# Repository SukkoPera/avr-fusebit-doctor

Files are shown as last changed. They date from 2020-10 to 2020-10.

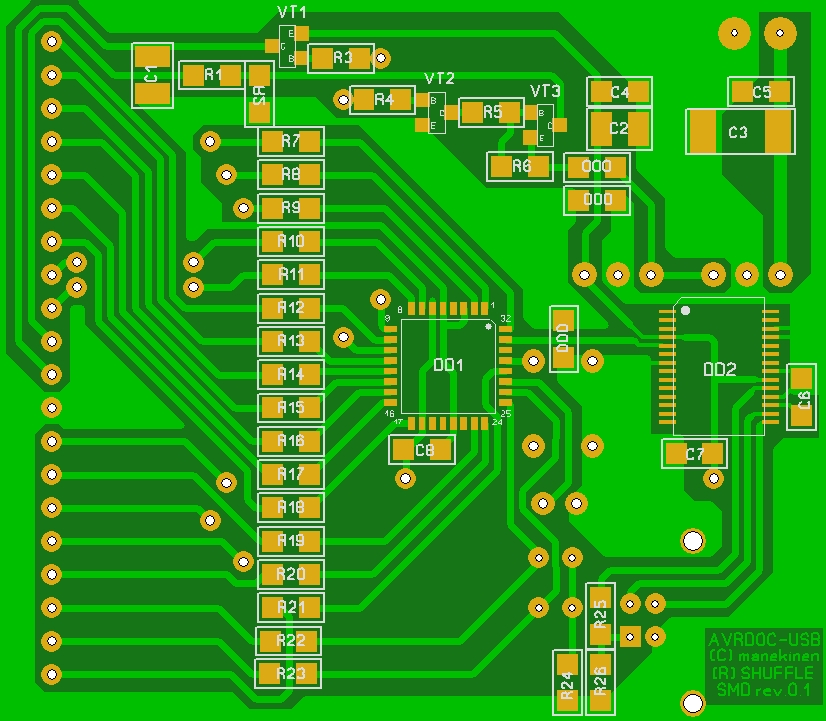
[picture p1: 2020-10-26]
SMD-pcb/avrdoc_main/shuffle_avrdocusb_botscr.JPG

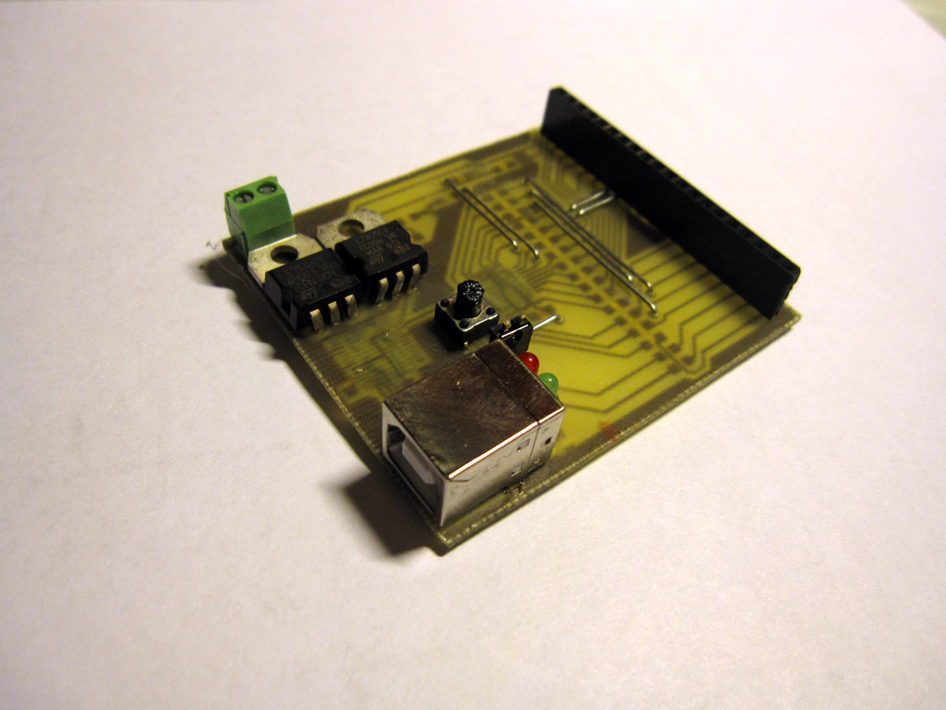
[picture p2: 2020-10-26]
SMD-pcb/avrdoc_photos/1_avrdoc_usb_top1.JPG

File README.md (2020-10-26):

# ATmega Fusebit Doctor (HVPP + HVSP): Fix the fusebits

ATmega Fusebit Doctor is a device for repairing dead ATmega (and ATtiny since v2.04) family AVR microcontrollers by writing correct fusebits. Most common mistakes or problems are a wrong clock source (CKSEL fusebits), disabled SPI programming (SPIEN fuse) or disabled reset pin (RSTDISBL fuse). This simple and cheap circuit will fix you uC in a fraction of a second. If in first case we can help ourself with clock generator, then in 2nd and 3rd cases bring uC back to life is impossible with standard serial programmer. Most of people do not decide to build parallel programmer because its inconvenient and its cheaper and faster to buy new uC.

Originally ATmega Fusebit Doctor was a project by Paweł Kisielewski (Manekinen). One day his website disappeared and the project was at risk of being lost forever. Luckily, I (SukkoPera) managed to salvage it with the help of Wayback Machine and decided to put it on GitHub, trying to preserve all the original contents and history. I hope people will contribute and help make it an even better project.

## High voltage programming
This circuit uses the parallel and serial high-voltage programming method. With those methods, we can talk to our "dead" chips which have reset or isp disabled:
- HVPP = High Voltage Parallel Programming
- HVSP = High Voltage Serial Programming.

## Supported chips
Code to this point supports 145 chips, but not all have been tested. Untested ones are listed *in italic*.

### 1kB
AT90s1200, *ATtiny11*, *ATtiny12*, ATtiny13/A, *ATtiny15*

### 2kB
ATtiny2313/A, *ATtiny24/A*, ATtiny26, *ATtiny261/A*, *ATtiny28*, *AT90s2333*, *ATtiny22*, ATtiny25, AT90s2313, *AT90s2323*, *AT90s2343*

### 4kB
ATmega48/A, *ATmega48P/PA*, ATtiny461/A, *ATtiny43U*, *ATtiny4313*, *ATtiny44/A*, *ATtiny48*, *AT90s4433*, *AT90s4414*, *AT90s4434*, ATtiny45

### 8kB
ATmega8515, ATmega8535, ATmega8/A, ATmega88/A, *ATmega88P/PA*, *AT90pwm1*, *AT90pwm2*, *AT90pwm2B*, *AT90pwm3*, AT90pwm3B, *AT90pwm81*, *AT90usb82*, *ATtiny84*, ATtiny85, *ATtiny861/A*, *ATtiny87*, *ATtiny88*, AT90s8515, *AT90s8535*

### 16kB
ATmega16/A, *ATmega16U2*, *ATmega16U4*, *ATmega16M1*, *ATmega161*, ATmega162, *ATmega163*, *ATmega164A*, *ATmega164P/PA*, *ATmega165A/P/PA*, ATmega168/A, *ATmega168P/PA*, *ATmega169A/PA*, *ATtiny167*, *AT90pwm216*, *AT90pwm316*, *AT90usb162*

### 32kB
ATmega32/A, *ATmega32C1*, *ATmega323/A*, *ATmega32U2*, *ATmega32U4*, *ATmega32U6*, *ATmega32M1*, *ATmega324A*, *ATmega324P*, ATmega324PA, *ATmega325*, *ATmega3250*, *ATmega325A/PA*, *ATmega3250A/PA*, *ATmega328*, ATmega328P, *ATmega329*, *ATmega3290*, *ATmega329A/PA*, *ATmega3290A/PA*, *AT90can32*

### 64kB
*ATmega64/A*, *ATmega64C1*, *ATmega64M1*, *ATmega649*, *ATmega6490*, *ATmega649A/P*, *ATmega6490A/P*, *ATmega640*, ATmega644/A, ATmega644P/PA, *ATmega645*, *ATmega645A/P*, *ATmega6450*, *ATmega6450A/P*, *AT90usb646*, *AT90usb647*, *AT90can64*

### 128kB
*ATmega103*, ATmega128/A, ATmega1280, *ATmega1281*, *ATmega1284*, *ATmega1284P*, *AT90usb1286*, *AT90usb1287*, *AT90can128*

### 256kB
ATmega2560, ATmega2561

## About
Just put your dead mega in socket, press the START button, and enjoy your good-as-new processor. There are three slots on board, for most common AVR’s, pins compatible with: ATmega8, ATmega16, ATtiny2313. There is also an extra goldpin connector with all signals so you can attach adapters:
- "#1 adapter" as HVPP extension, for 20pin ATtiny26 compatible and 40pin ATmega8515 compatible processors.
- "HVSP adapter" for 8pin and 14pin HVSP processors

Or make your own adapters for other types of processors, in trough-hole or surface-mounted, you can use the breadboard for this – just connect signals to correct pins. How? Check your AVR datasheet, go to "memory programming” and then "parallel programming” – check the signal names, all signals are described under the DIP40 slot. In doctor memory there is a lot of free space so project may be developed all the time. One sided PCB with 55mm x 92mm dimensions. On top side you need to solder several jumpers, or, make this PCB as double sided – choose yourself.

Resistors from R7 to R23 may be in 100ohm to 10K, but i suggest from 470ohm to 1K.

ATTENTION! While mounting the DIP40 slot, you must to remove it pins from 29 to 37. These pins must not have electrical contact with inserted uC pins, traces runs there only to make the board smaller (onesided). Take a look at pic on the left, these you must remove from slot.

## Usage
The ALLOW ERASE jumper allows doctor to erase whole flash and eeprom memory, if it is open, doctor will never erase memory but may not cure device if lockbits are enabled, so you choose.

After insert dead uC and press the START button, doctor will initiate the parallel or serial high-voltage programming mode. This is chosen automatically, device will recognize HVSP adapter and start to work in HVSP mode. After that, doctor wait for high state at RDY/BSY line. Then, read device signature and check if it supports it. Next, memory erase is performed if user allows that. Then lockbits are checked, and if they not blocking device, doctor sets all fusebits to fabric, having regard to whether there are extended fusebits or not. Some of older AVR have only one byte of fuses – LOW – and this is also included. After
fusebits are verified, the proper leds is flashed.

### Leds explanation
- Green on – patient successfully cured, fusebits repaired. If lockbits are enabled, just verify fusebits with factory ones – and if they ok – light up green.
- Red on – signature problem, can’t read, no device in socket, or no such signature in database.
- Green flashing – signature ok, fusebits are wrong. Lockbits enabled, chip erase permission required (read below).
- Red flashing – signature ok, no lockbits, but for some reason can’t write new fusebits.

## Terminal
Note that terminal is not needed, device works without pc, and all we want to know we get from leds.

You can find extra RS232 output, and connecting this to the terminal, sends all information about fixing process – see exemplary printscreens in gallery. All the info is sent "on the fly" via uart. Use proper converter to connect this with pc. If you have COM port for RS232, use MAX232 based converter (eg this). If you are using laptop, use a USB converter.

### Terminal settings
- Baudrate: 4800
- Parity: none
- Data bits: 8
- Stop bits: 1
- Handshake: none

## Other
Use one of the following microcontrollers as the doctor-chip: ATmega8, ATmega88, ATmega88P, ATmega168, ATmega168P, ATmega328, ATmega328P – and their newer/low-voltage "A” or "L” versions.

Use stabilized 12V supply voltage. Higher voltage can damage the patient chip!

Code was written based on high-voltage parallel and serial programming section of datasheet of suitable AVRs.

### Fusebits
Internal 1MHz clock, and enabled EESAVE bit – see README file.

If you use a brand new chips as doctor, you don’t need to change anything – 1MHz clock is already set as default. EESAVE bit is optional. It disallows to erase the eeprom when firmware is actualized, eeprom is used to store the fixed chips counter which is sent trough UART.

## Manual Mode
UPDATE 2.1X ADDS NEW FUNCTIONALITY!

Send your own fuses and locks trough terminal, talk with chips with broken signature. If you connect terminal TX pin to PCB RX pin – manual mode will be enabled automatically. This requires TX-terminal pin to be HIGH and OUTPUT when idle. It must pull up the 10K pulldown. If this condition is not met, doctor will work in normal – automatic mode.

### HowTo
First, doctor will read signature. And if fail, it will ask to type signature manually.

Type two last bytes of signature in HEX (4 chars) and hit enter.

Then doctor will try to read the chip depending on given signature.
When this succeeds, select an option:
1. Write fusebits: this will perform a fuse write cycle with fuse-values from buffer (default).
2. Modify fusebits: this will let you to type fuses manually, values in buffer will update. Type one byte in HEX (2 chars) and hit enter. Repeat for each byte (if exist).
3. Set lockbits: type new lock value in HEX (2 chars) and hit enter – do this with caution! Remember that unused bits are always 1! E.g. if want to enable LB1 and LB2, type FC (11111100).
4. Erase the chip: This will just erase the chip and locks, it requires the "allow erase" jumper for safety.
5. End: exit programming and drop voltages, now you can safely remove the chip.

Do not pay attention to the LEDs when in manual mode – they will just blink randomly :).

## License
Manekinen's original licensing terms say:

> Any modifications allowed, do not remove this README! from archive. Do not remove info from pcb and code.
>
> Any usage of this project in commercial/profit purposes is prohibited.

They are a bit vague but they seem to match [CC BY-NC-SA 4.0](https://creativecommons.org/licenses/by-nc-sa/4.0/?ref=chooser-v1) pretty well, so I think that can be used whenever a formal license is needed.

Note that the firmware sources are not available. They have never been disclosed as far as I know.

## FAQ – Frequently Asked Questions (and Answers)

Q: No sign of life, no leds are working.
A: Critical bugs on pcb, poorly programmed chip.

Q: Red led is on.
A: Chip si not recognized. Make a voltage measurements. In idle, measure voltages on +12 RESET and +5 SUPPLY at female goldpin connector – you should get 0V or close to 0V on both. After the START button is pressed, you should get close to +12V and 5V for one second. If not, check transistors, if they are ok and if they are soldered ok.

Q: Red led is on.
A: Bugs on pcb, traces are packed densely and its very possible that you have invisible gap, shortcut, or dry joint. Check everything with multimeter, but PRECISELY.

Q: Red led is on.
A: Connect device to the terminal to get repair log. Press start to receive infos.

Q: Received "Init programming...” and nothing more – OR – received signature is "00 01 02” or "FF FF FF”.
A: Chip is broken, or there still are bugs on pcb – look above.

Q: Received signature is "1E 90 00", "1E 1E 1E", or something familiar (meaningful data).
A: Chip is good, it initiates, look for shortcuts on DATA, BS, XA lines.

Q: Green led is on / "Verifying... – OK!" received, but chips don’t work with standard programmer.
A: You can be 100% sure that fuses are fixes, chip have hardware ISP damaged or it have some other damage.

Q: What are "Read Signature... FAIL!" and "Trying T2313 pinout... OK" doing in log?
A: All the 20pin chips need to be treated individually. First, device tries to read chip with standard schematic, and if it fails ("FAIL!”), then it tries to use schematic for 20pin T2313 compatible chips and then chip is read properly. This is normal behavior, this not a bug.

Q: What are `<[2J` trashes doing in log?
A: This is a terminal clear screen sequence, turn on the "VT-100” emulation in terminal settings.

Q: I’m trying to type data into terminal but no chars appearing.
A:Make sure you set handshake to NONE in terminal settings.

Q: After typing data into the terminal, I can’t confirm them with return key and can’t type next ones.
A: When pressing return, your terminal must have to send the CRLF chars, if not, check your settings.

Q: This still doesn’t help me, I tried everything but still have the problem.
A: Ask in comments below :) Post firmware version and pcb version with which you try to work, paste the repair log.

Q: Are all those 1K series resistors (R7 through R23) really needed here?
A: No, you can build the circuit without them. But remember, if for some reason out patient will not enter in the programming mode and continue with its code, then logic state conflict will occur between two microcontrollers which can damage them permanently. These resistors are to protect the circuit against such situations. I strongly recommend to build it exactly as schematic says.

Q: Pull-down resistors for 12V and 5V lines (R24 and R27) are heating up quite strongly in manual mode, and whole circuit takes more power, can i change them for something higher value?
A: Yes, but circuit can work incorrectly with some of the patients. When idle, voltages should be near 0V, and when powering on or off, their edges should have proper
steepness to provide good timing (see entering high voltage programming in datasheet). Because only simple bipolar transistors are used, these resistors guarantee above requirements. The interesting case is an ATtiny2313 problem when all the fuses were correctly burned, without one, the RSTDISBL. As it showed up, because of bad edges of 12V reset voltage, this uC although was working in parallel mode, but not in high voltage, so it was not allowing to change that fuse – this is my own interpretation so i can be wrong.

Q: My chip is read properly but doctor can not write new fuses, allow erase is enabled.
A: If the ISP programmer acts the same way, then your chip is damaged, nothing can do.

Q: Without a patient, circuit acts awkward, it freezes, and goes on when i put my finger near the traces.
A: This circuit is not meant to be used without a patient. It acts in such way because when entering in programming mode, it is waiting for a high state on the RDY pin from patient. This pin is not pulled down and works as high impedance input, so electrostatic charge from your finger is read as high state and code goes on further.

Q: Chip names are not appearing in the log, i see "no names in 8kB ver" instead.
A: Chip names are not displayed in 8kB versions of the firmware, i.e. for ATmega8 and ATmega88 – because names don’t fit in such memory space. If you want the names, use ATmega168 or ATmega328 chip and burn proper firmware. ALWAYS use the newest version of the firmware. Hex and bin files are the flash memory files, use one of them. No need to program eeprom memory.

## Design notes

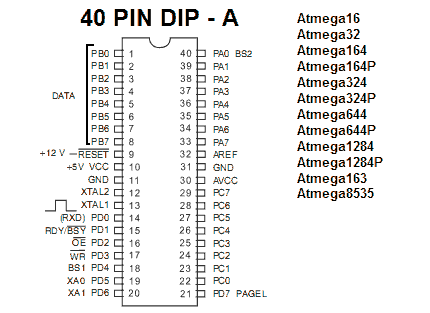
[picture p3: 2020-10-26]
sockets/40pin-onboard.gif

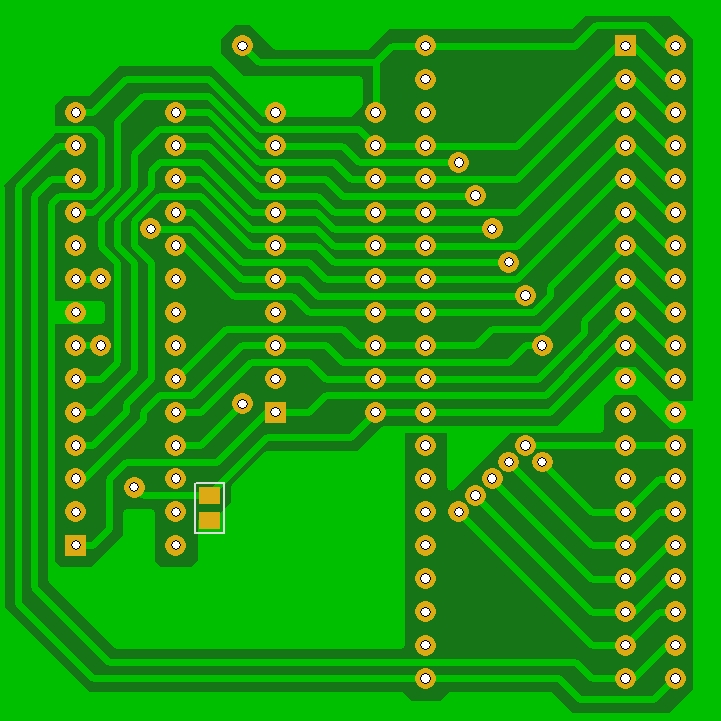
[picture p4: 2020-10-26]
SMD-pcb/avrdoc_adapter/shuffle_avrdocusb_botscr.JPG

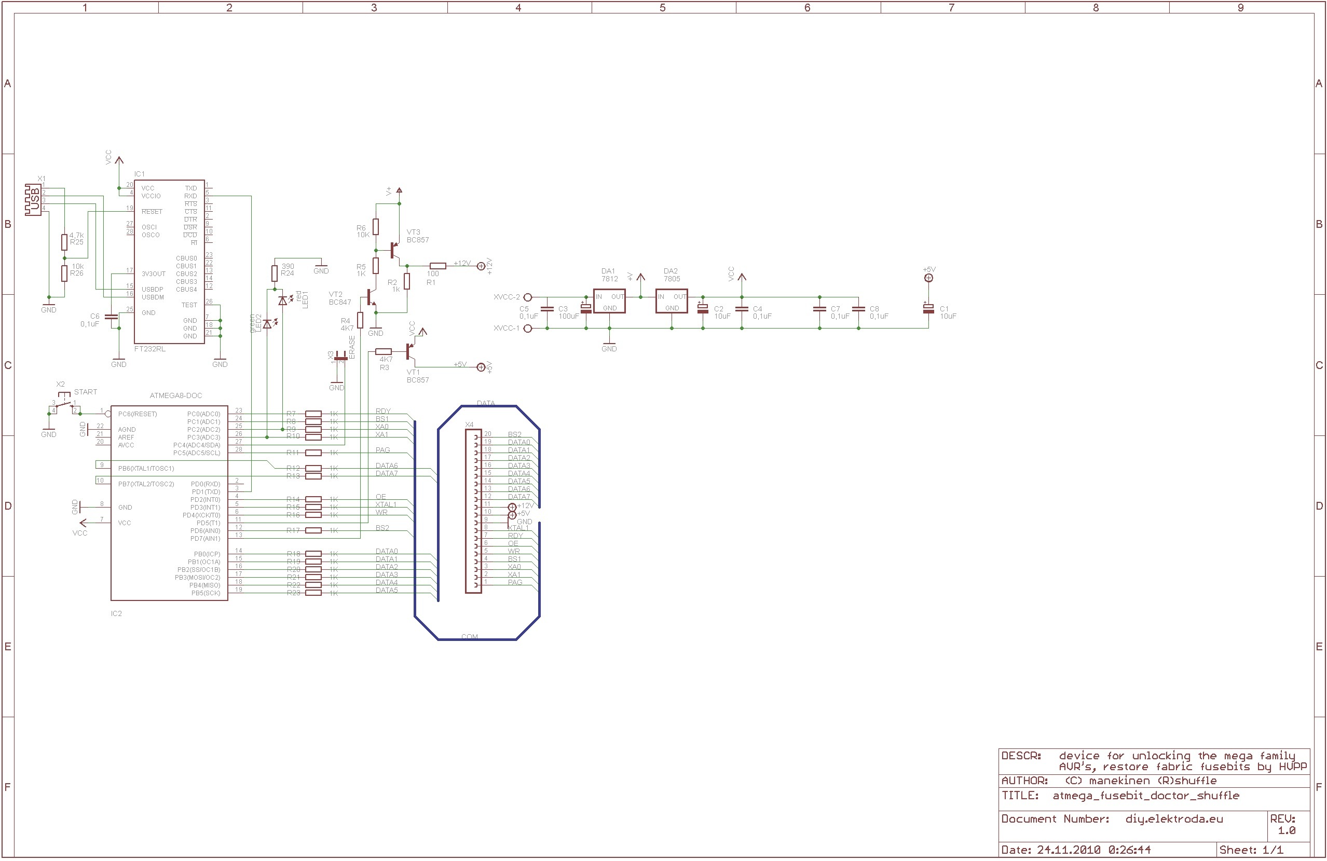
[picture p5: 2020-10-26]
SMD-pcb/shuffle_avrdocusb_scheme.jpg

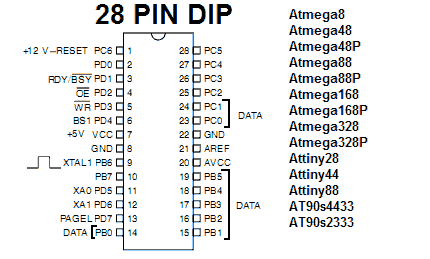
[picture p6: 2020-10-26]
sockets/28pin-onboard.gif

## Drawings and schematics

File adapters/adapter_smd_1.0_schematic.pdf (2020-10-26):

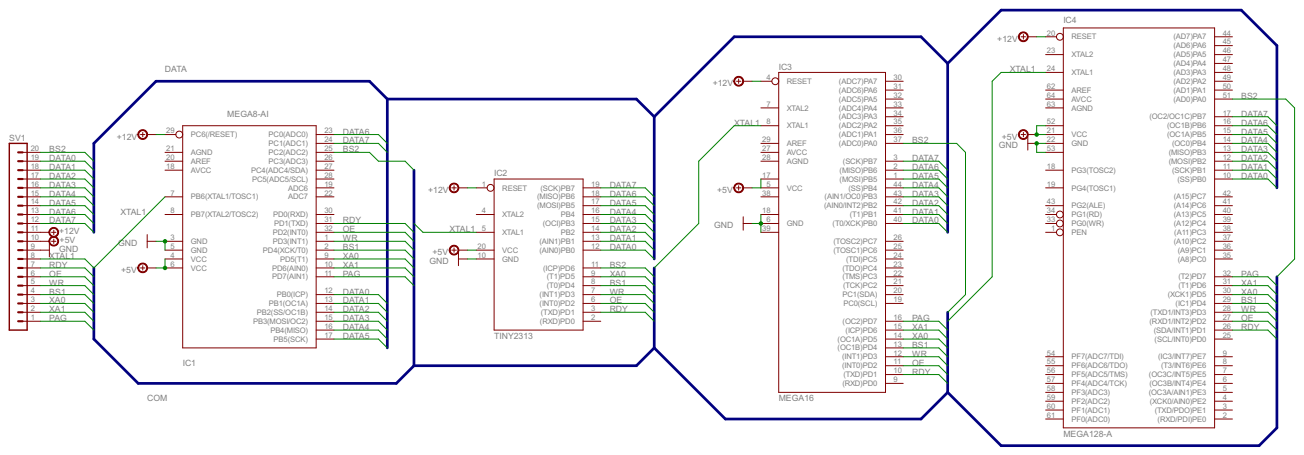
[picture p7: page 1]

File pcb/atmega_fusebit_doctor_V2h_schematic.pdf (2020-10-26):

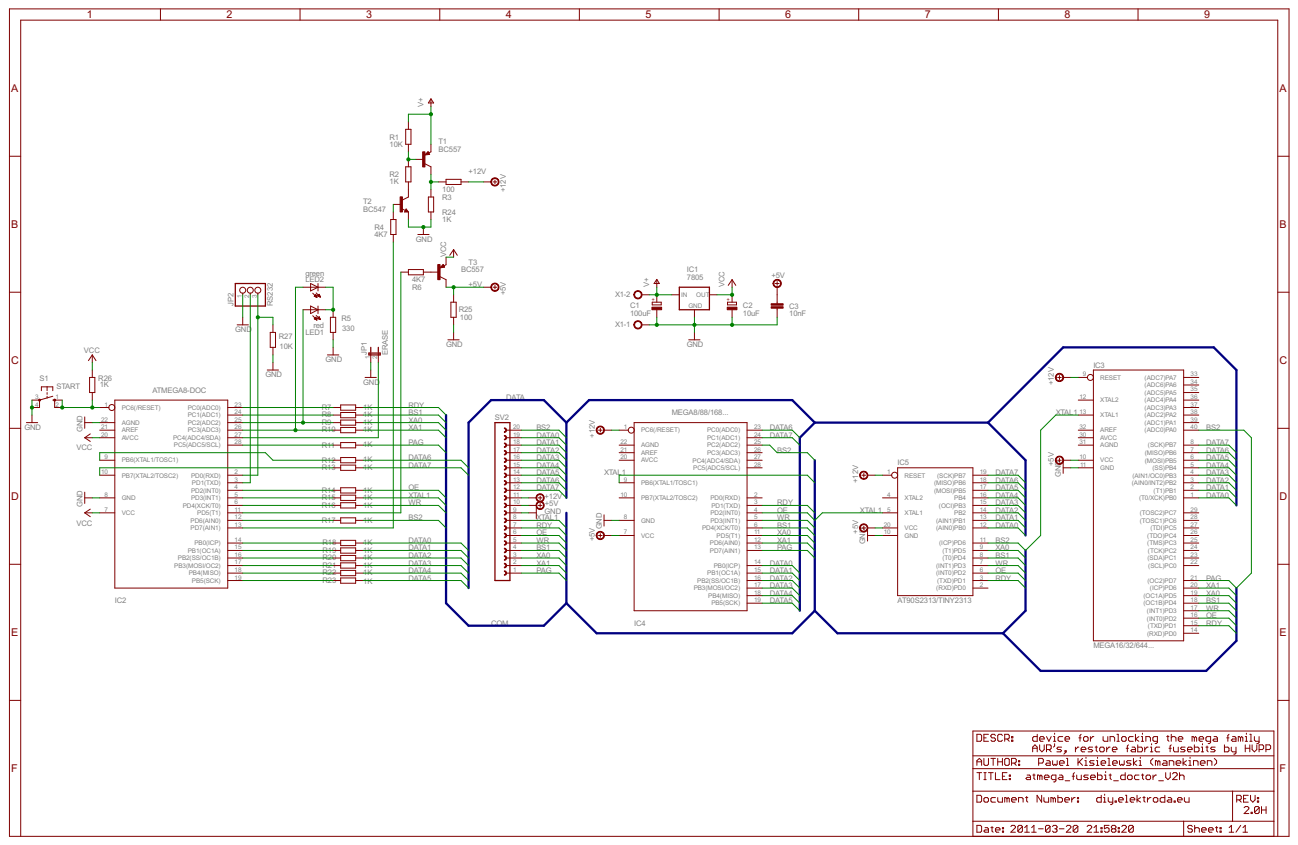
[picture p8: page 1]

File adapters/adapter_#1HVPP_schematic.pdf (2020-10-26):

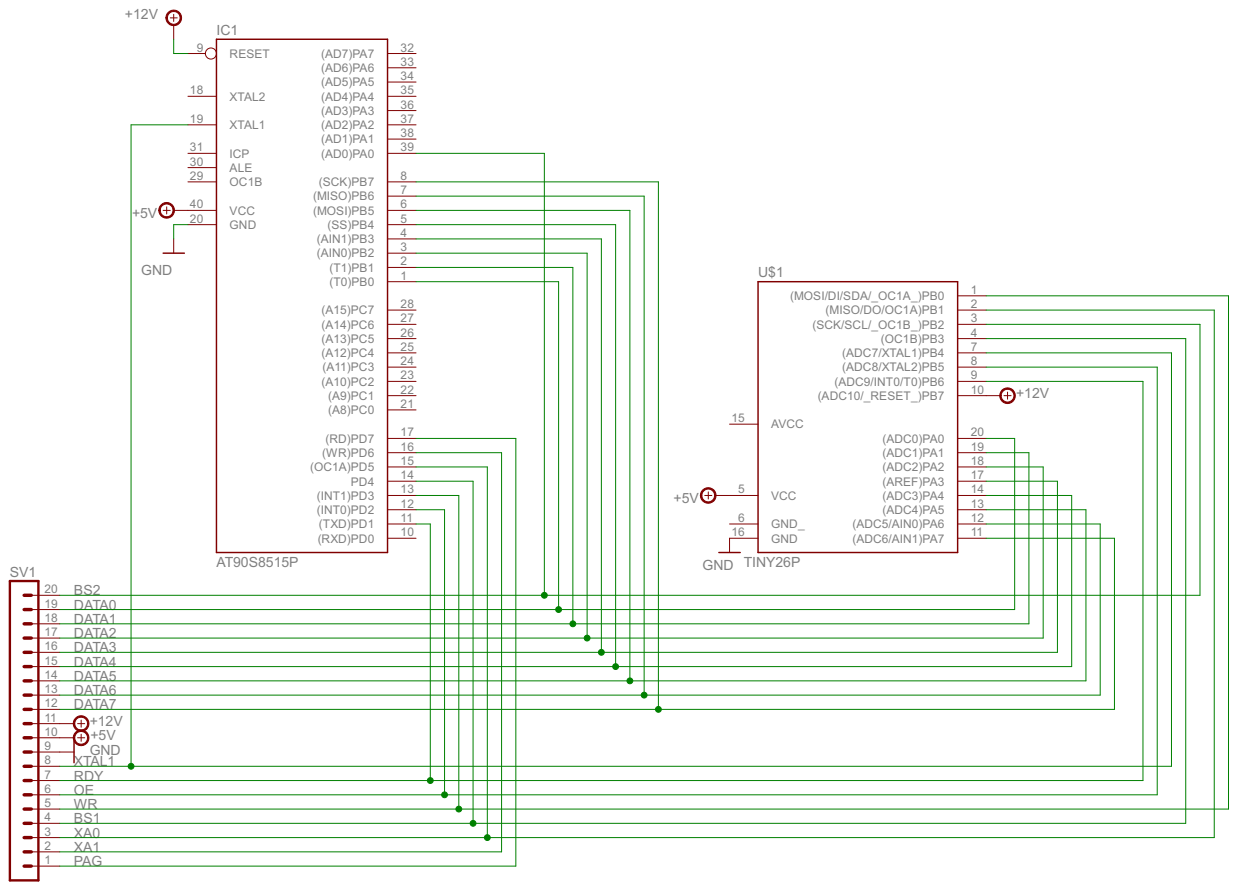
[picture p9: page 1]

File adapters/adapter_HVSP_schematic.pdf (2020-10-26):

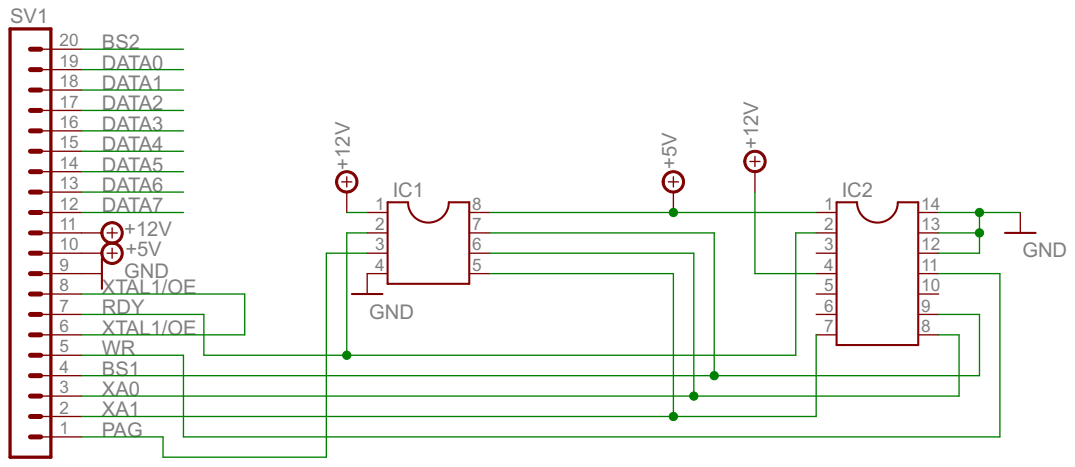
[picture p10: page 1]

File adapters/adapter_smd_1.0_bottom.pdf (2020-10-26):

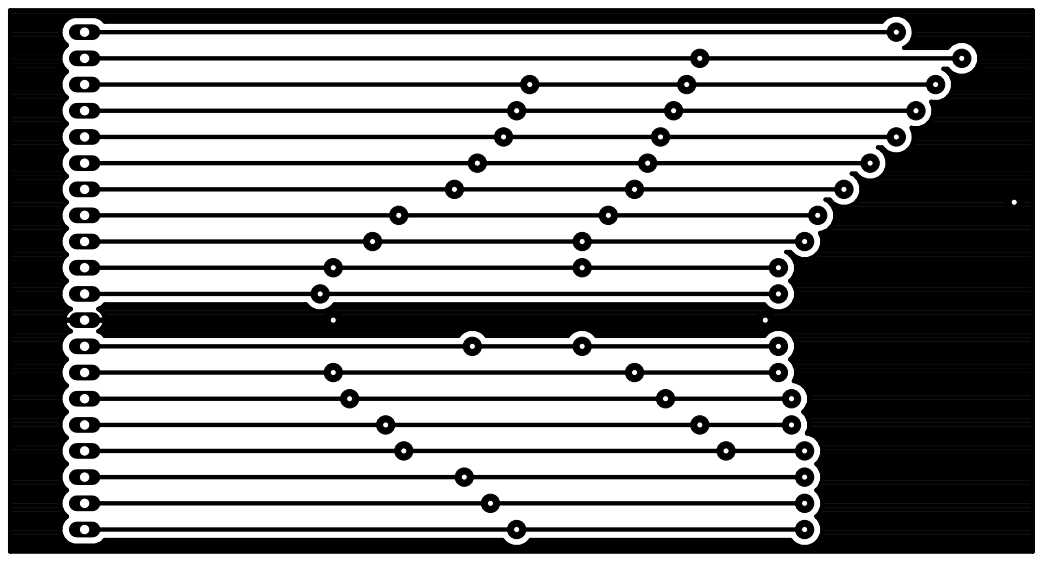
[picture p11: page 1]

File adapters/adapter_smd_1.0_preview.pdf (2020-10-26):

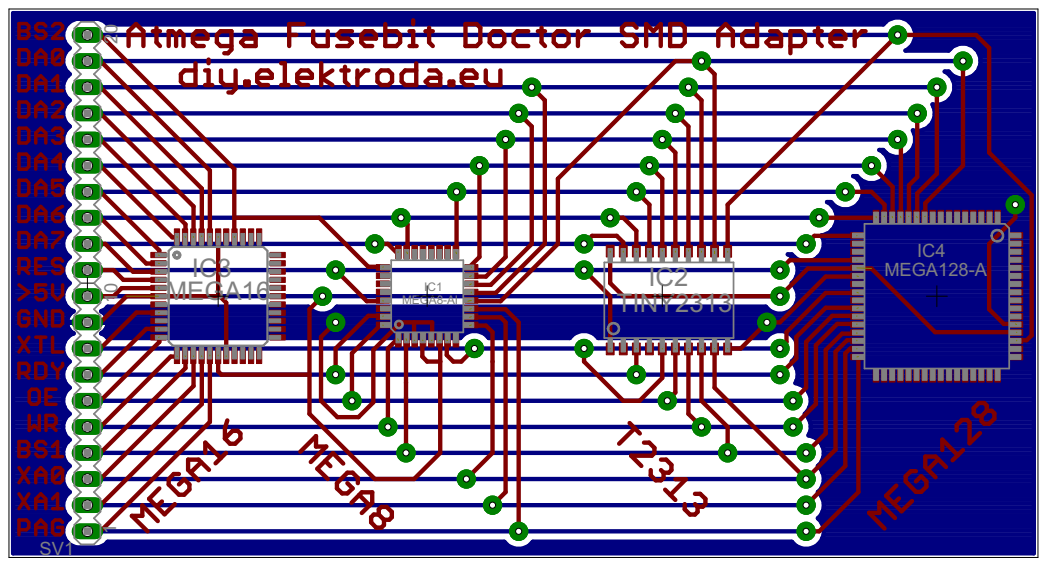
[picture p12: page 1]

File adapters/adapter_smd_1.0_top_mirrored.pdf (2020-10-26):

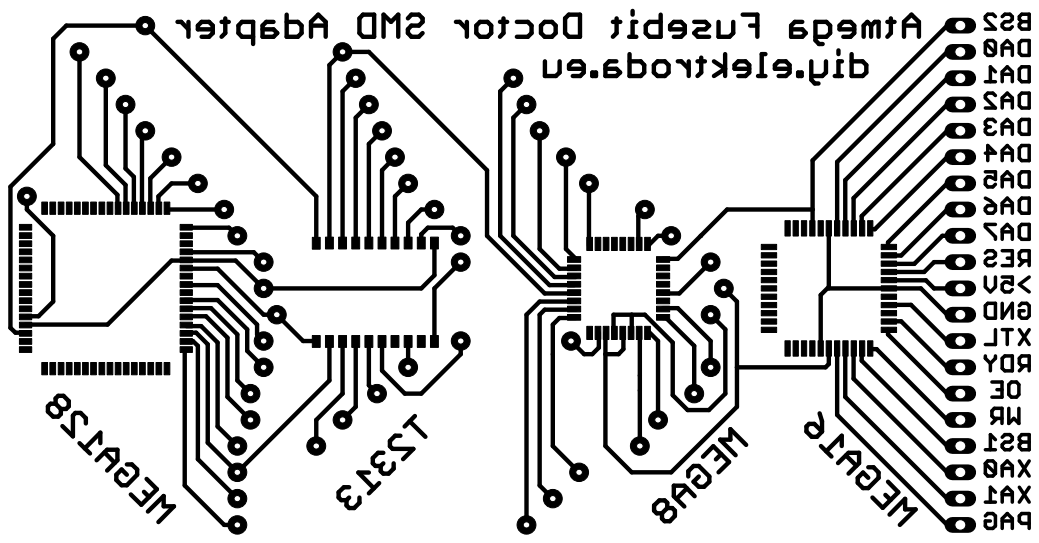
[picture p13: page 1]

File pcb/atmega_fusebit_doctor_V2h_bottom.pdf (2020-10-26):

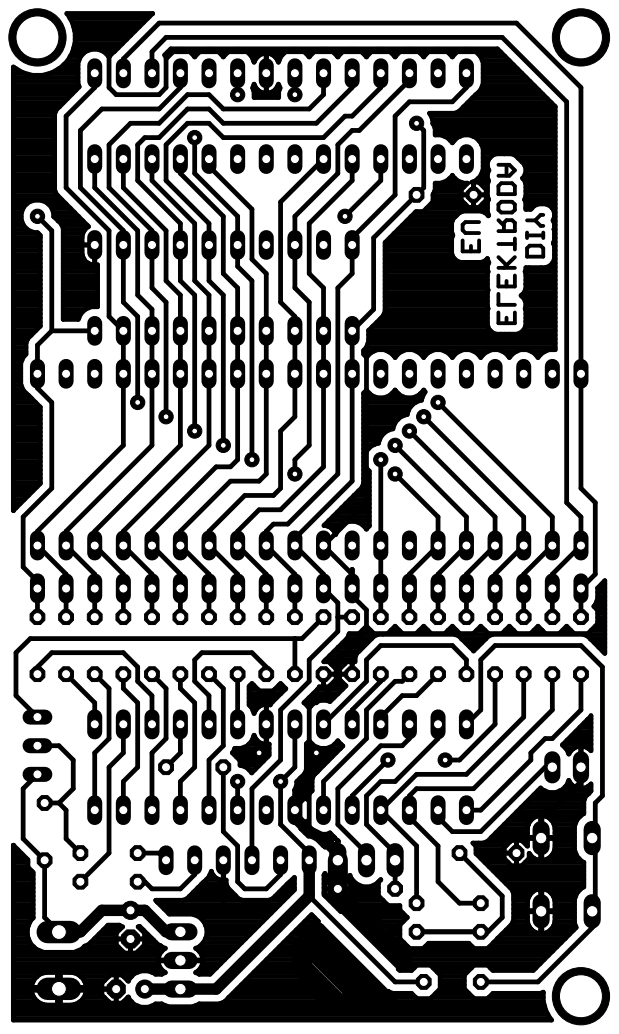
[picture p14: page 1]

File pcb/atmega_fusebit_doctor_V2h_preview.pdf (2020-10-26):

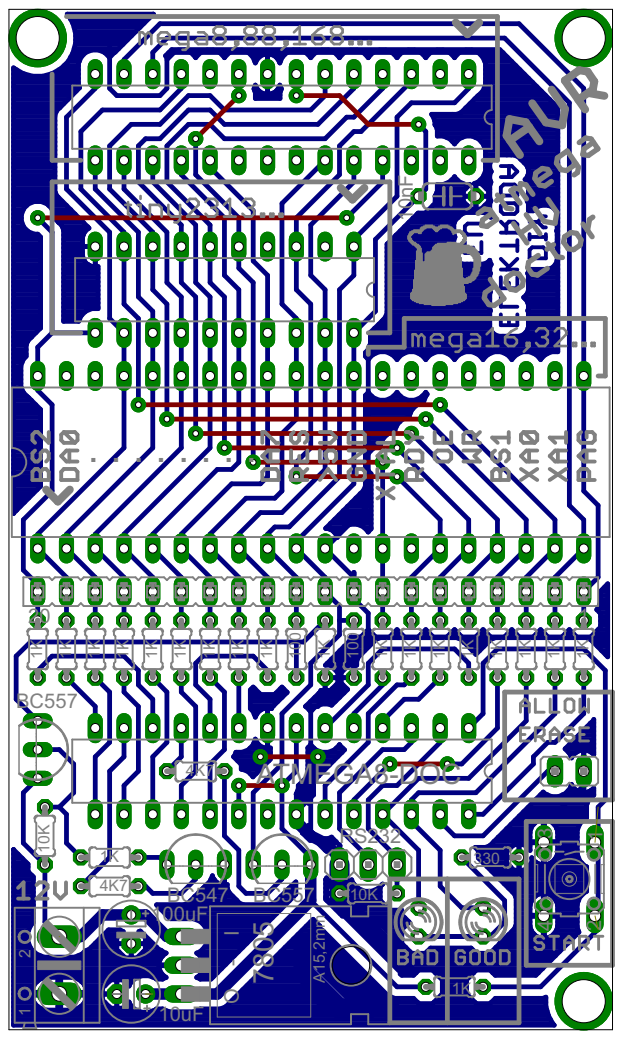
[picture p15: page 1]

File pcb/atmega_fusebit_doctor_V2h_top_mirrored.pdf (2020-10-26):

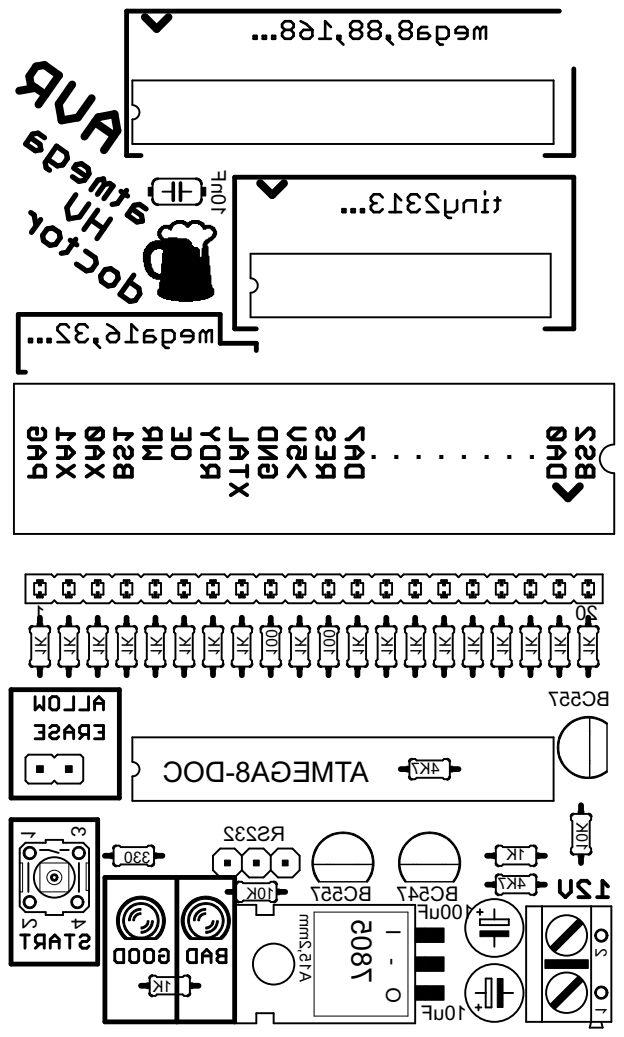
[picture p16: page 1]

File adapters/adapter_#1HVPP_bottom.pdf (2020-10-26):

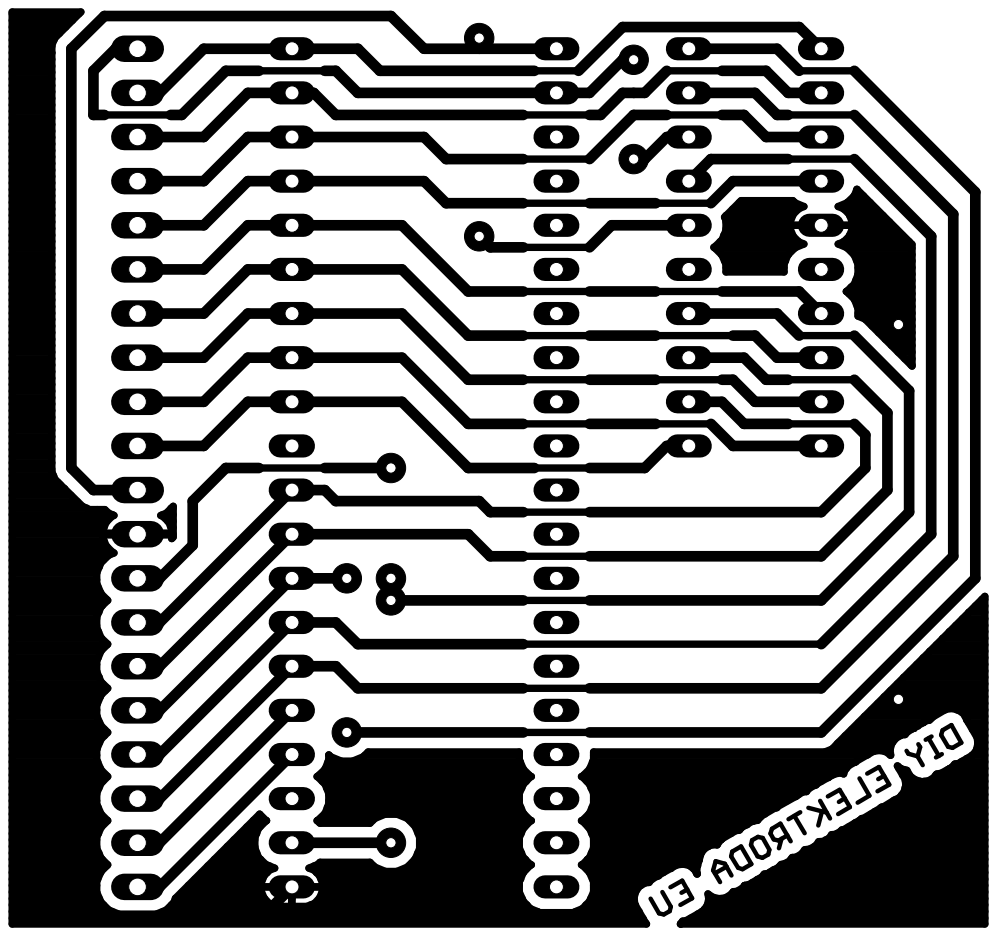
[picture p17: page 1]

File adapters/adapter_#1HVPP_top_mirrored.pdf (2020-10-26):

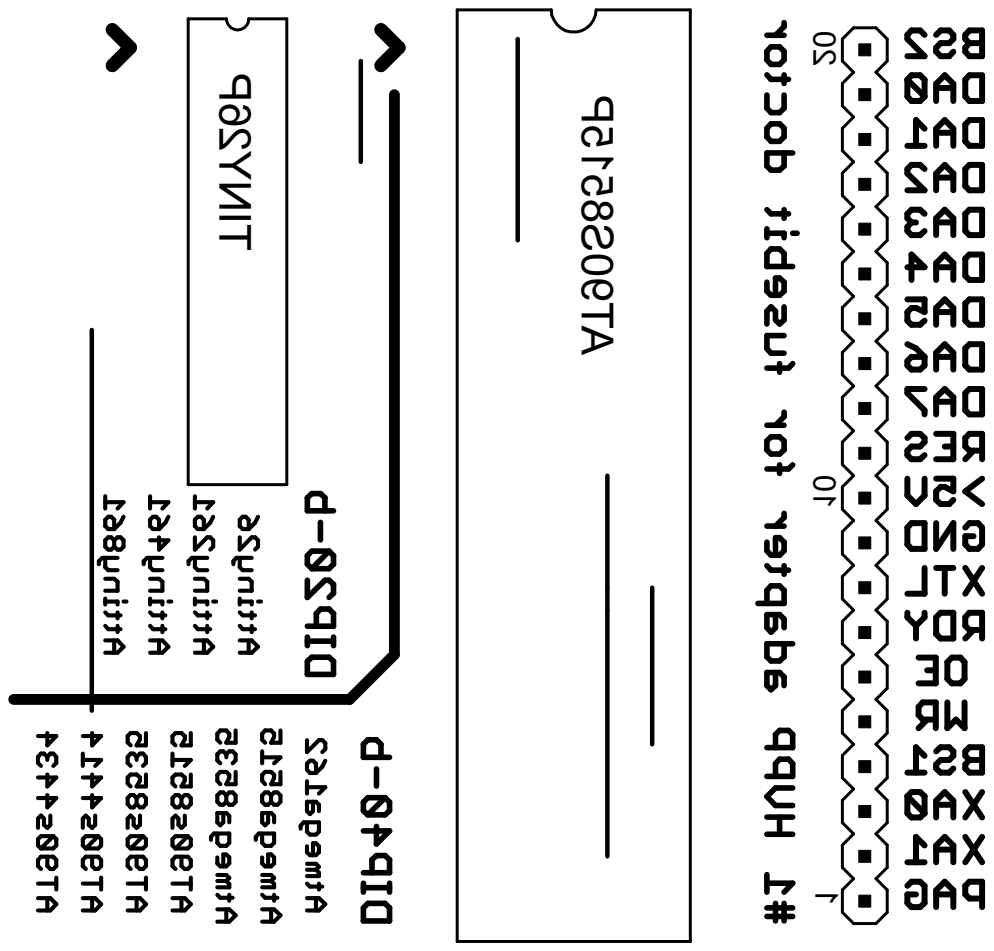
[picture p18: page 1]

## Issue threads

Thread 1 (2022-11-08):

So I built this and here are the issues I encountered

nickd4, 2022-11-08:
In my build the tracks were a bit skinny due to a problem with my etchant and I decided to press ahead anyway even though I ended up having to do quite a bit of debugging to fix broken tracks and such. If doing it again, I would start by checking every track by multimeter against the PCB diagram, I put off doing this at first as I was thinking I'd have to go by the schematic which would be much slower.

In the process of fixing the PCB issues I would connect the power wires, test, disconnect the power wires, put it back under the microscope to look for opens, repair tracks etc, and repeat. And at some stage I accidentally reversed the 12V power :( Things appeared to still work, but eventually I realized the BC557's and possibly the BC548 had become leaky, I avoided replacing them for a long time :(

My debugging method for the BC557s and BC548 was to remove doctor chip and probe patient socket's RESET and VCC lines while connecting the transistor base resistors to GND and VCC and verify that the transistor can apply the +5V and +12V and that it goes away when transistor base is open or in inactive state. (I used a dummy load, but the circuit already has pulldowns installed anyway).

So all of this tedious debugging wasted a day and a night, but eventually I was satisfied that the hardware was correct, at least I could not find any more issues by very careful inspection and probing. And the build mostly works, BUT, I still seem to have some residual issues and I will list them here.

1. Unreliable starting, and I reckon this is because RESET does not have a capacitor installed to debounce the switch. It would depend on how much stray capacitance is in your circuit and switch and how bouncy your switch is, but keep in mind that short reset pulses with clock running are illegal. So I installed a 1.0 nF capacitor across the switch (AVR has Schmitt input for RESET so slow rise is OK). I believe my fix has made the problem go away, but would have to remove and re-test to be really sure.

2. Unreliable with HVPP parts, it will work for a while (press switch say 10 times) and then stop working for a while (press switch say another 5 times and eventually it will come good again). And I reckon this is because the patient AVR does not have its AVCC (and AGND on older parts that have a separate AGND) connected properly. HVSP is reliable for me and I suspect it's because those smaller pin count parts that rely on HVSP mode, do not have separate analog supply pins. Also it may depend on which parts you are using, the original author mentioned that not all parts have been tested. I happen to have a lot of AT90S2313, AT90S4433, AT90S8535 in stock (very old parts as I was an early adopter), these chips have separate AGND and don't work without it. So that may be why the problem wasn't reported earlier. OTOH, I also see the problem with an ATMEGA8 so perhaps the issue is actually with my build.

3. Refuses to erase chip, even though I have the "allow erase" jumper installed and have probed it carefully to be certain the circuit is built correctly. I suspect a firmware issue, but again it may be my build. :( To debug this I may create a diagnostic firmware that reports the state of all lines as seen from the chip, with the pull-ups enabled. I could then try shorting each line to ground one at a time to test it.

At this stage I haven't finished debugging issues 2 and 3 due to lack of time and hardware. (I need to grab some different sized sockets from the office and try wiring their AVCC, AGND and possibly even AREF and then use them as interposers, I don't have any sockets at home because I normally just cut off the right amount of SIP socket and construct my own sockets since SIP socket is more versatile). But I decided to make a report anyway, as others might have encountered similar issues. Let me know!

All going well, I'll probably re-make this in KiCAD and do an open source firmware. I really love the way the author has designed this, even the removal of 9 pins from the 40-pin patient socket was kind of clever when you look at his layout, but unfortunately I need those pins back to add the AVCC/AGND connections. So I'll probably end up redoing the layout and shuffling the pins a bit. I may also redesign the RESET/VCC transistor part and clean-room the rest, in which case we could open source it fully.

SukkoPera, 2022-11-08:
Thanks a lot for your testing and detailed review! I'm not sure this board is suitable for hand-etching, I don't know if the tracks are thick enough. I only have a single one, professionally-made and it seems to work fine, but I think I've only used it a couple of times.

It would be great to have a fully open alternative. I don't really like the need to remove those 9 pins, so please avoid that if you remake this from scratch :).

Good luck!

nickd4, 2022-11-08:
Thanks for the feedback, and for putting the repo up. I hope it can become a hub for maintaining the project as far as feasible, hopefully you can donate a little time for approving PRs, closing issues etc (otherwise I am happy to assist).

I think it is acceptable for hand etching, the feature size is not too small and the oval pads help a lot. However, what it requires is (1) an aggressive etchant so you etch quickly and remove before there is significant under etch, and (2) etch compensation to enlarge the mask slightly to compensate for under etch. But in my build of this project the etching took a whole hour :( And there was significant under etch, this also happened recently with another project and wasted a lot of time so I switched to a different chemistry with initially good results but then a turn for the worse when reusing the new etchant.

The way I prepare masks normally is with KiCAD exporting to Gerber, then a Linux utility (maybe called gerbview or something like that) to convert to 1200dpi PNG bitmaps. Then I run a Python utility I wrote that adds the etch compensation, basically wherever it sees a dark pixel in the input image it "ors" in a 4x4 circle in the output image. So every track gets 3 pixels wider and every inter-track space gets 3 pixels narrower. This works for me normally. However, in this case I did not apply my procedure and just used the provided images.

SukkoPera, 2022-11-08:
Sure, I will approve PRs but I can also add you directly as a project collaborator if you prefer.

I have never done home-etching, I really don't want to mess with chemicals, I wouldn't know how to do it safely enough :).

AlucardXP, 2023-03-15:
@nickd4  When I originally came across the project, there was also a tutorial on how to etch your own boards. Mine came out decent with the method that I used (laser print onto a glossy magazine page, transfer the ink to copper clad, etch with sketchy radio shack solution). I had a lot of issues with the traces being unreliable. There were also a lot of ground areas that were too close to other traces.

Now that its been over 10 years later, I went to revisit the project I was working on (recovering a locked AT90S2313 with a disabled RESET pin). Most my traces test ok but it won't work anymore. Most likely due to thin traces. With how cheap you can get circuit boards printed and cut, it may just be time to redesign the board and upload a version that anyone can use to get printed.

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

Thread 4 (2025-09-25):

New PCB design that might help

marshfolx, 2025-09-25:
Someone released a new PCB design based on this project : [https://oshwhub.com/etberzin/avr-gao-ya-bing-xing-jie-suo-qi](https://oshwhub.com/etberzin/avr-gao-ya-bing-xing-jie-suo-qi). License: CC BY-NC-SA 4.0. The design works ok based on description.

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

**Features**

- on board boost circuit generating 12V from 5V input;
- power through usb type c port;
- ATmega8A DIP-28 as controller;
- DIP-28 socket, and QFP-64, QFP-32 pad for patient;

**Schematic & Pcb**

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

SukkoPera, 2025-09-25:
Thanks for the information. I like the new features but not so much that it now uses SMD components.

Closed 2025-09-26.

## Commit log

2020-10-26 Update SMD PCB with contents from latest shuffle_avrdoc_usb.rar
2020-10-26 Add SMD adapter PCB from atmega_fusebit_doctor_smd_adapter_1.0.rar
    [adapter_smd_1.0.brd, adapter_smd_1.0.sch]
